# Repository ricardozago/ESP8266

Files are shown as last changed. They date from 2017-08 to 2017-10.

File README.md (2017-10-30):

# Guia inicial do ESP8266

O ESP8266 é um microcontrolador com grande capacidade de processamento (80 MHz de processador com 96 KB de RAM para dados), com suporte a redes Wifi. [Seu artigo na Wikipédia](https://en.wikipedia.org/wiki/ESP8266) é um bom ponto de partida para entender melhor. Ele está disponível em vários empacotamentos, onde a versão chamada de ESP-01 pode ser utilizada como um chip para fornecer acesso Wifi para o Arduino (ironicamente possuindo muito mais capacidade de processamento que o próprio Arduino Uno R3). O ESP8266 sozinho pode ser utilizado no lugar do Arduino utilizando a mesma IDE para processamento, no entanto nosso foco aqui é utilizá-lo como um periférico no Arduino.

Pode ser necessário atualizar o Firmware no ESP-01. A versão mais atual (para a versão com 512 KB, 4 Mb de memória ROM, esp8266_nonos_sdk_v2.0.0_16_08_10) pode ser encontrada na pasta do Github ou [aqui](http://espressif.com/en/support/download/sdks-demos). Aparentemente a versão 2.1 não é compatível com a versão de 4 Mb de memória ROM. Os arquivos para atualização do Firmware eagle.flash.bin e eagle.irom0text.bin estarão no arquivo compactado na pasta bin/at/noboot. Também serão utilizados os arquivos esp_init_data_default.bin e blank.bin na pasta /bin. Para facilitar eles estão na pasta [Firmware AT 4 Mb](https://github.com/ricardozago/ESP8266/tree/master/Firmware%20AT%204%20Mb) deste repositório.

Para gravar o firmware podem ser utilizados diversos softwares. Existe uma ferramenta muito rica escrita em Python chamada [esptool.py](https://github.com/espressif/esptool), no entanto usaremos o gravador (flash_download_tools_v3.4.9.2_0), disponível na pasta ou em seu [site oficial](http://www.espressif.com/en/support/download/other-tools). Para o ESP entrar no modo de gravação da imagem é necessário iniciá-lo com a porta GPIO0 aterrada. Também é possível colocar o reset no terra, aterrar o GPIO0, remover o reset do terra e posteriormente o GPIO0.

O [site do Filipeflop](http://blog.filipeflop.com/wireless/upgrade-de-firmware-do-modulo-esp8266.html) demonstra a montagem do circuito necessária. Também existe um projeto de um shield para o Arduino Uno R3 para facilitar a gravação, disponível [nesta pasta](https://github.com/ricardozago/ESP8266/tree/master/ESP-01%20Firmware%20Flasher), uma imagem da placa é mostrada abaixo.

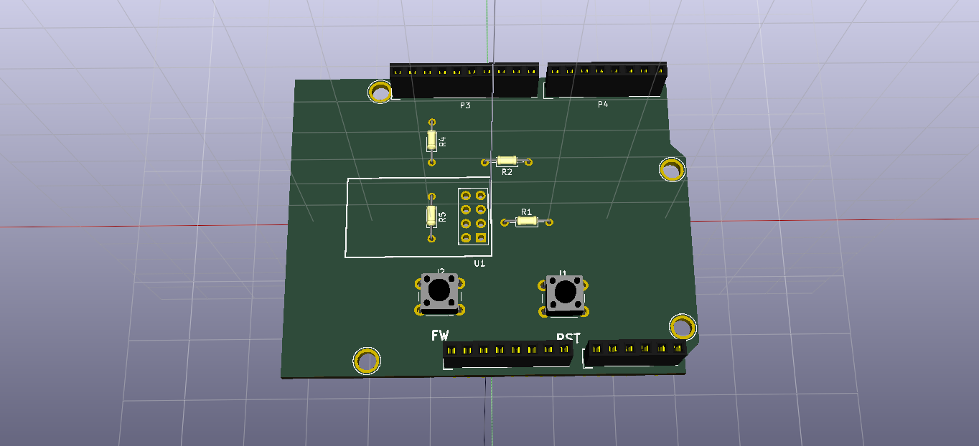
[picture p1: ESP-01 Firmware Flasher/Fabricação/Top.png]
Gravador Placa


Para realizar o microcontrolador Atmel do Arduino não interferir na gravação do Firmware é necessário enviar um Sketch vazio para o Arduino. Como o padrão:

    void setup() {
      // put your setup code here, to run once:

    }

    void loop() {
      // put your main code here, to run repeatedly:

    }

As configurações do gravador de ROM podem ser as mesmas da imagem abaixo:

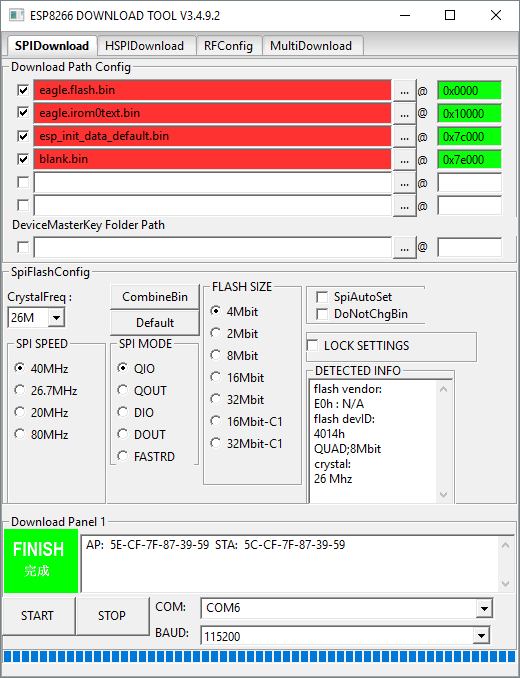
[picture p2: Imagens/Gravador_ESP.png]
Gravador


# Ainda na interface do gravador

O baudrate padrão do ESP é 115200, pode-se utilizar um software de terminal para comunicação, como o [Termite](https://www.compuphase.com/software_termite.htm). Entre nas configurações do termite e em Transmitted text marque a opção:

    Append CR-LF
    
Esta opção adiciona um retorno de cursor e uma nova linha ao comando, necessário para o ESP entender que você acabou de enviar o comando. Para verificar a comunicação com o terminal envia o comando:

    AT

O ESP deverá responder com:

    OK

O Arduino Uno R3, possui apenas uma porta de comunicação UART, que é conectada do chip FTDI para conversão para USB. O ESP pode ser conectado nessa mesma interface, mas isso acarreta problemas de comunicação e dificuldade de programação, já que você terá 3 sistemas "conversando" em uma interface onde apenas deveriam existir 2 sistemas. Uma solução é utilizar uma biblioteca que transforma um GPIO qualquer do Arquino em porta serial, o que acarreta problemas de comunicação em baud-rates elevados, portanto é necessário dominuir o baudrate da interface UART do ESP. O comando abaixo, em um firmware atualizado faz isso:

    AT+UART_DEF=19200,8,1,0,0
    
Agora você já está pronto para conectar o ESP diretamente no Arduino. Utilize o Shield, cujo projeto está disponível na [pasta](https://github.com/ricardozago/ESP8266/tree/master/Arduino%20Shield).

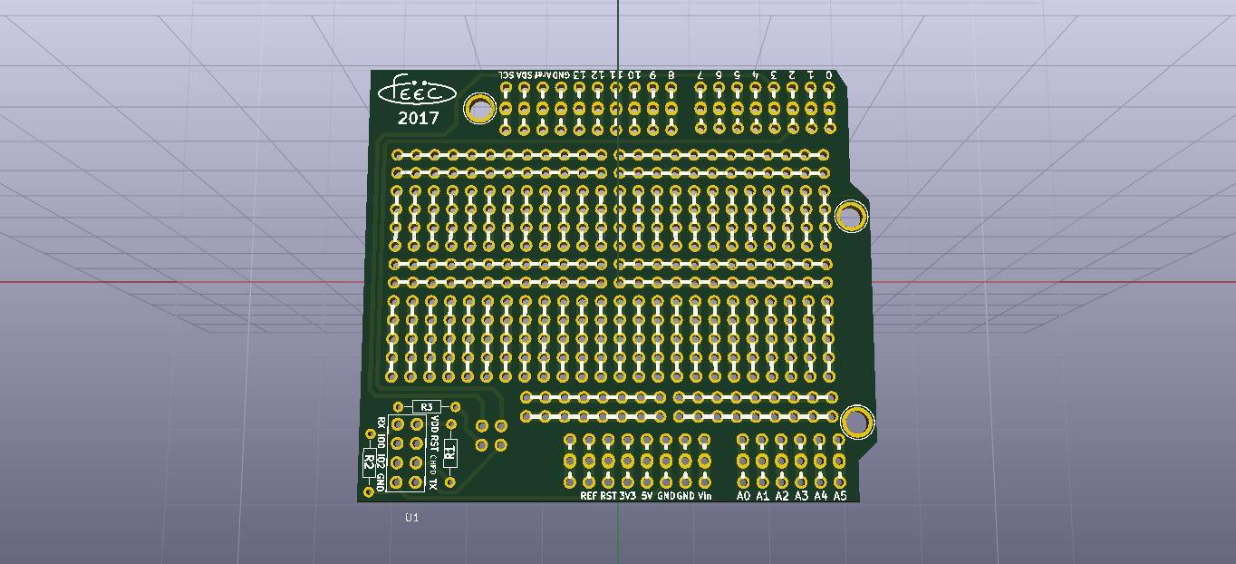
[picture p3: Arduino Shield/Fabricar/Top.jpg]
Shield com ESP

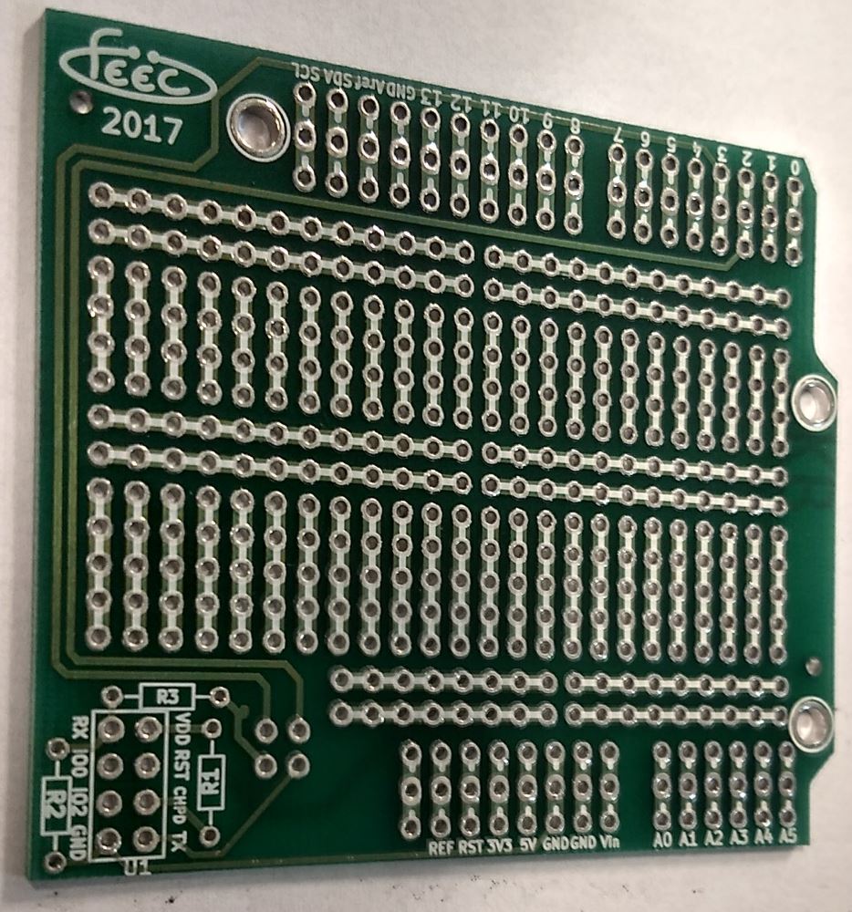
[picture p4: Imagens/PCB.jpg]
Shield fabricado

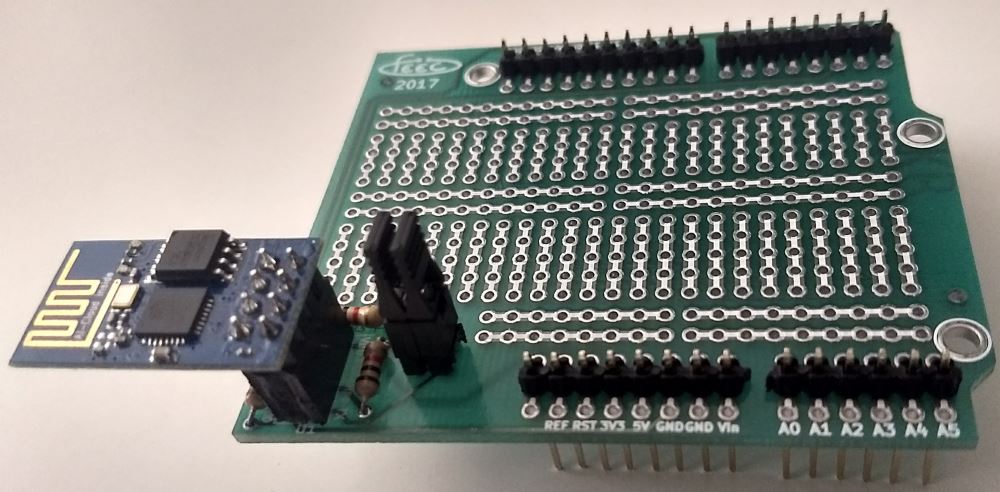
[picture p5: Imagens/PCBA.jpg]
Shield fabricado com ESP


O Sketch [disponível aqui](https://github.com/ricardozago/ESP8266/tree/master/ESP-Espelho) copia os comandos enviados via terminal para o Arduino para o ESP e vice-versa. Isto permite conversar diretamente com o ESP e enteder melhor o seu funcionamento.

Inicialmente envie o comando:

    AT+GMR

A versão do firmware será exibida, por exemplo:

    AT version:1.3.0.0(Jul 14 2016 18:54:01)
    SDK version:2.0.0(656edbf)
    compile time:Jul 19 2016 18:43:55
    OK

Utilize o comando abaixo para verificar em qual modo de operação o ESP está funcionando.

    AT+CWMODE?

Os possíveis modos de operação são:

1 = Cliente
2 = Ponto de acesso
3 = Cliente + Ponto de acesso

O comando abaixo passa para o modo cliente:

    AT+CWMODE=1
    
É possível fazer uma busca nas redes disponíveis com:

    AT+CWLAP
    
Ele retornará uma lista de redes disponíveis. Por exemplo:

    +CWLAP:(5,"eduroam",-86,"d8:c7:c8:78:19:02",1,6,0)
    +CWLAP:(0,"Unicamp-Configuracao",-64,"d8:c7:c8:78:18:d0",1,15,0)

O comando abaixo se conecta a alguma das redes disponíveis:

    AT+CWJAP="ssid","pass"
    
Mostra o IP:

    AT+CIFSR
    
O abaixo se desconecta:

    AT+CWQAP
    
Lembrando, as configurações são salvas. Quando você desliga e liga o ESP, ele continua com as mesmas configurações anteriores, como o baud rate e a última rede conectada.

[Este tutorial do Filipeflop](http://blog.filipeflop.com/wireless/esp8266-arduino-tutorial.html) é um bom ponto de partida para criação de um simples webserver. Apenas alterei o modo de conexão, onde no Filipeflop é necessário um roteador para realizar a conexão, enquanto no meu o próprio ESP é o roteador e os dispositivos se conectam nele. Minha versão modificada está disponível [aqui](https://github.com/ricardozago/ESP8266/tree/master/Arduino%20%2B%20ESP%20-%20p%C3%A1gina%20WEB/Ler_Portas).

Para [alterar o nome da rede](https://github.com/espressif/ESP8266_AT/wiki/CWSAP) no modo AP utilize o comando:

    AT+CWSAP="nome_da_rede","senha",chl,ecn
    
onde se a ecn  é igual a 0 a criptografia está desabilitada. Caso queira habilitar: WEP (1), WPA-PSK (2), WPA2-PSK (3) e WPA/WPA2-PSK (4). Já chl é o canal que a rede é criada.

[Esta página](http://allaboutee.com/2015/01/02/esp8266-arduino-led-control-from-webpage/) possui um interessante exemplo para atuar utilizando uma página Web com o Arduino+ESP. Também disponível [neste repositório](https://github.com/ricardozago/ESP8266/tree/master/Arduino%20%2B%20ESP%20-%20p%C3%A1gina%20WEB/Atuar_IO).

# Observações

Todos os layouts de placa desta pasta utilizam o software [Kicad](http://kicad-pcb.org/), a placas foram desenvolvida utilizando como modelo o Shield para arduino disponível como exemplo do Kicad.

Seu layout foi feito a pedido do professor [Fabiano Fruett](http://www.dsif.fee.unicamp.br/~fabiano/) para uso em disciplinas na Faculdade de Engenharia Elétrica e de Computação (FEEC) da Unicamp.

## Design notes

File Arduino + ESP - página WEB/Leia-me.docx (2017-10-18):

Ler_Portas

O programa Ler_Portas cria uma rede sem fio com o nome padrão do ESP (neste caso ESP_D364D1) sem senha. Conecte-se a essa rede e depois entre no endereço 192.168.4.1.

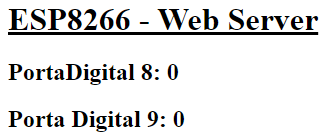
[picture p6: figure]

Esta página mostra o estado das portas 8 e 9.

Atuar_IO

No atuar_io é necessário conectar-se na mesma rede sem fio. Mas a página agora é local, abra o arquivo Página-Web.html que está na mesma pasta.

A página web possui 3 botões, que alteram o estado dos pinos de entrada e saída 11, 12 e 13.

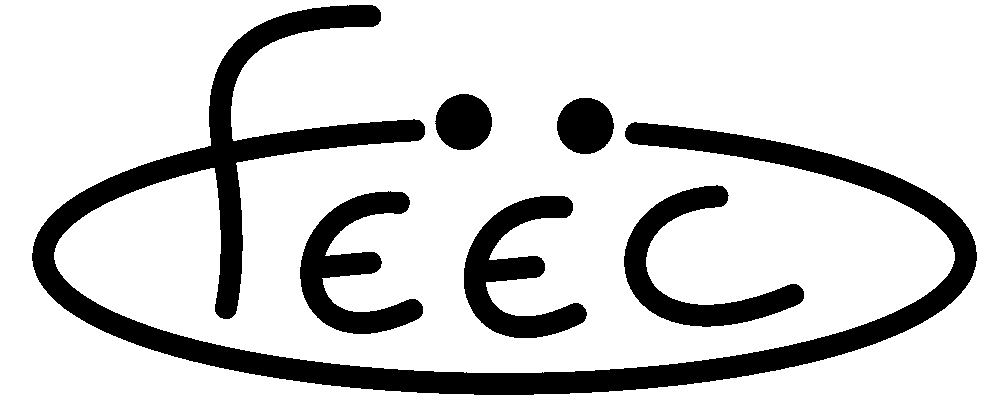
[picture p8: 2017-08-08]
Arduino Shield/feec2.png

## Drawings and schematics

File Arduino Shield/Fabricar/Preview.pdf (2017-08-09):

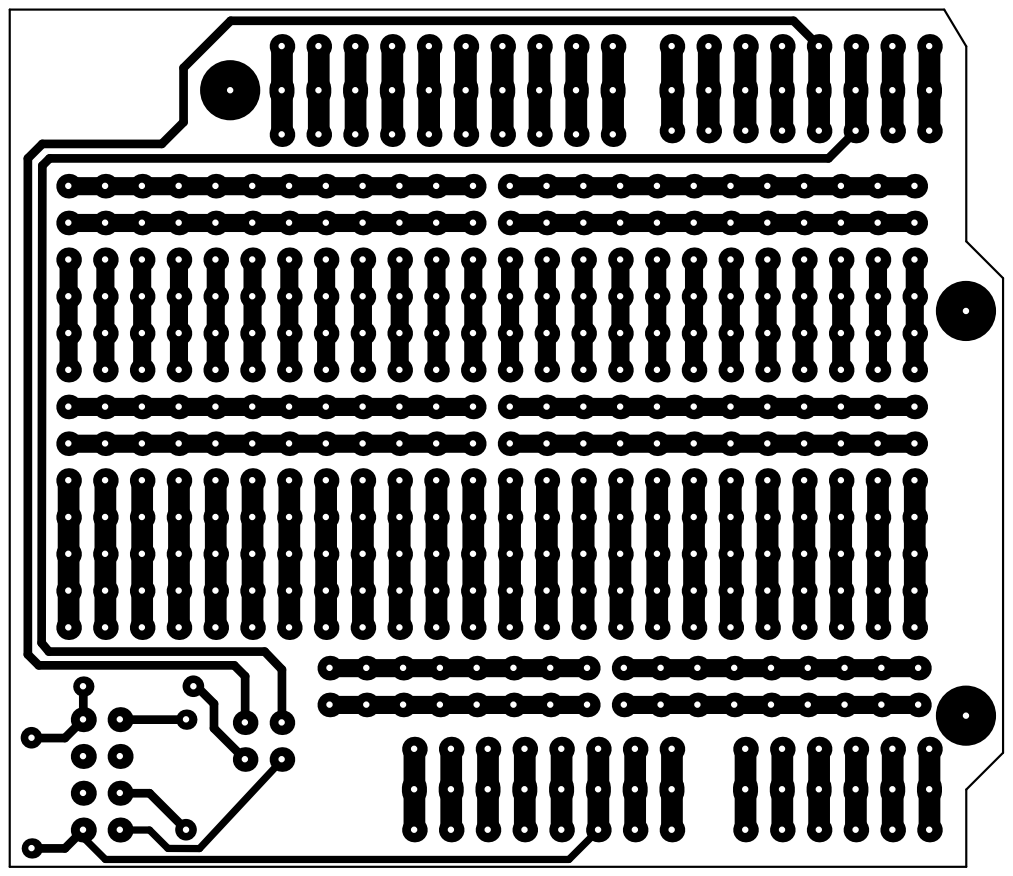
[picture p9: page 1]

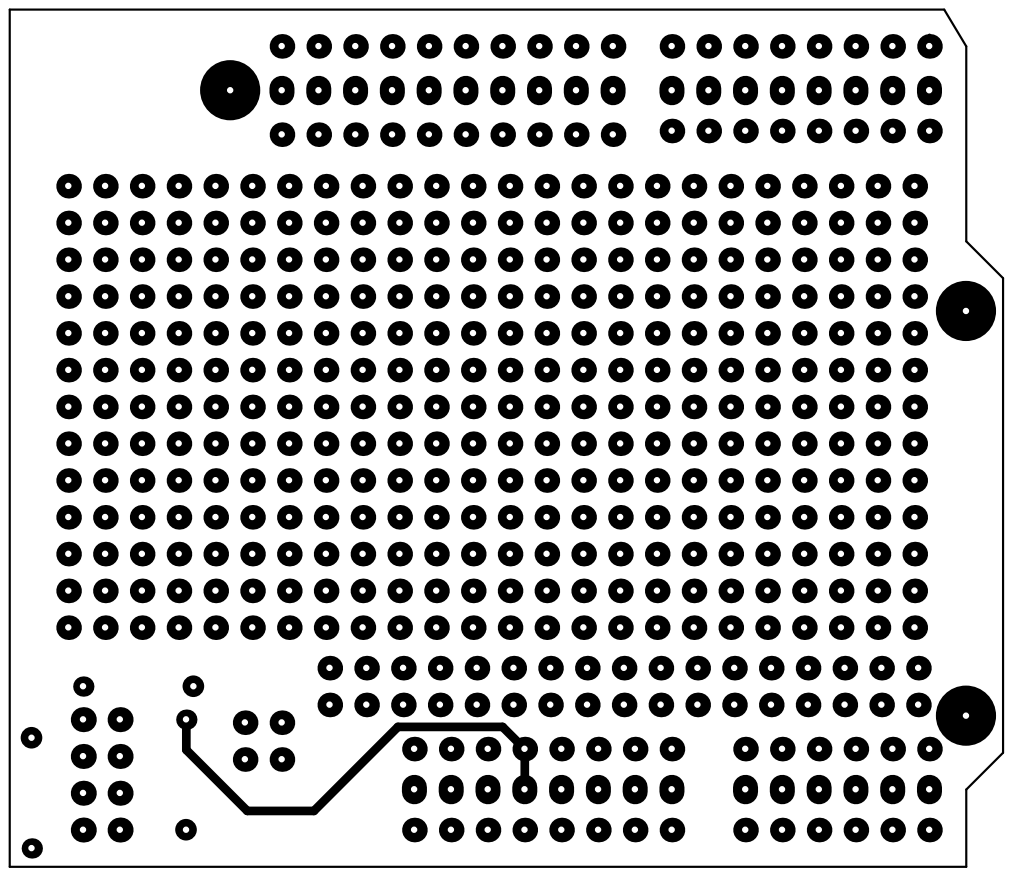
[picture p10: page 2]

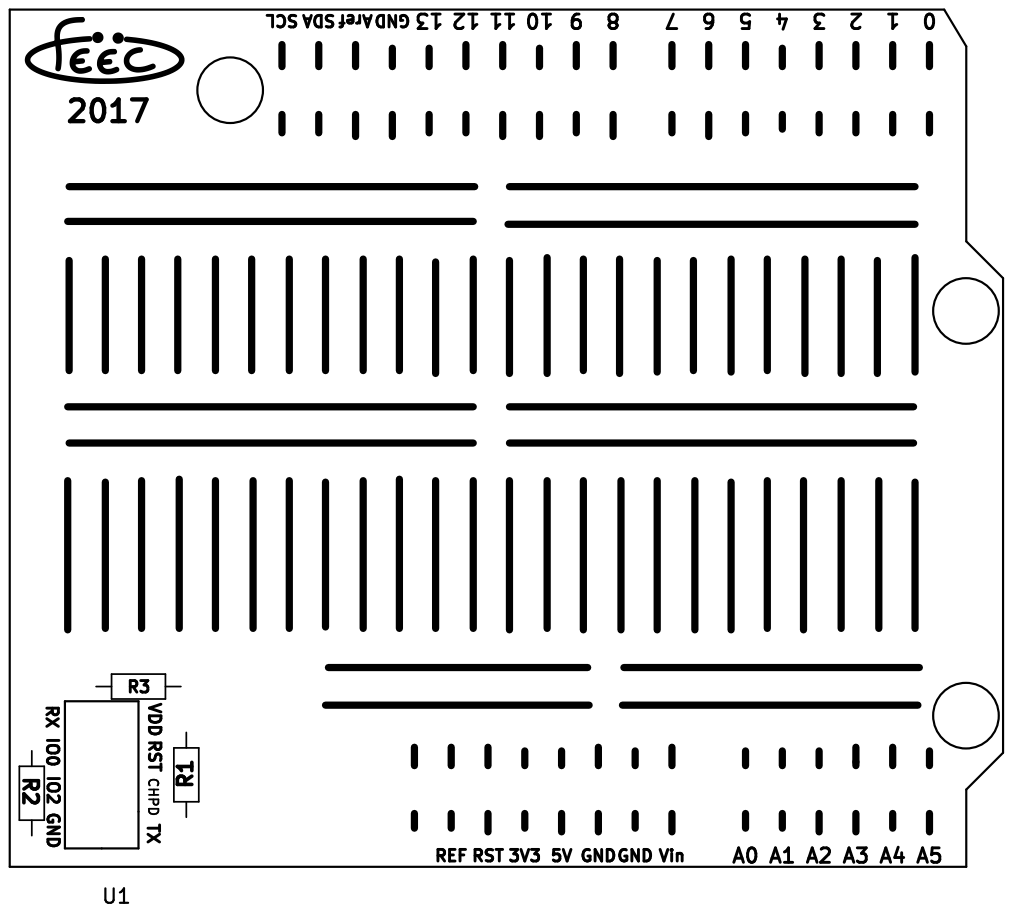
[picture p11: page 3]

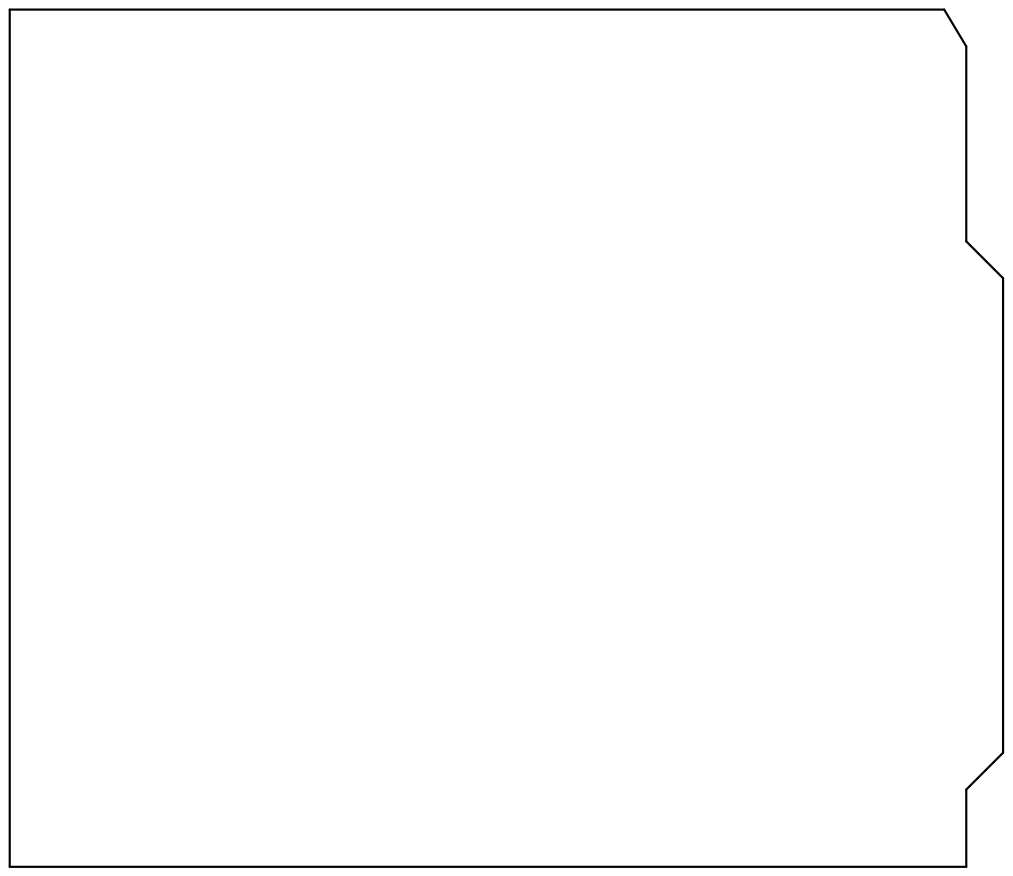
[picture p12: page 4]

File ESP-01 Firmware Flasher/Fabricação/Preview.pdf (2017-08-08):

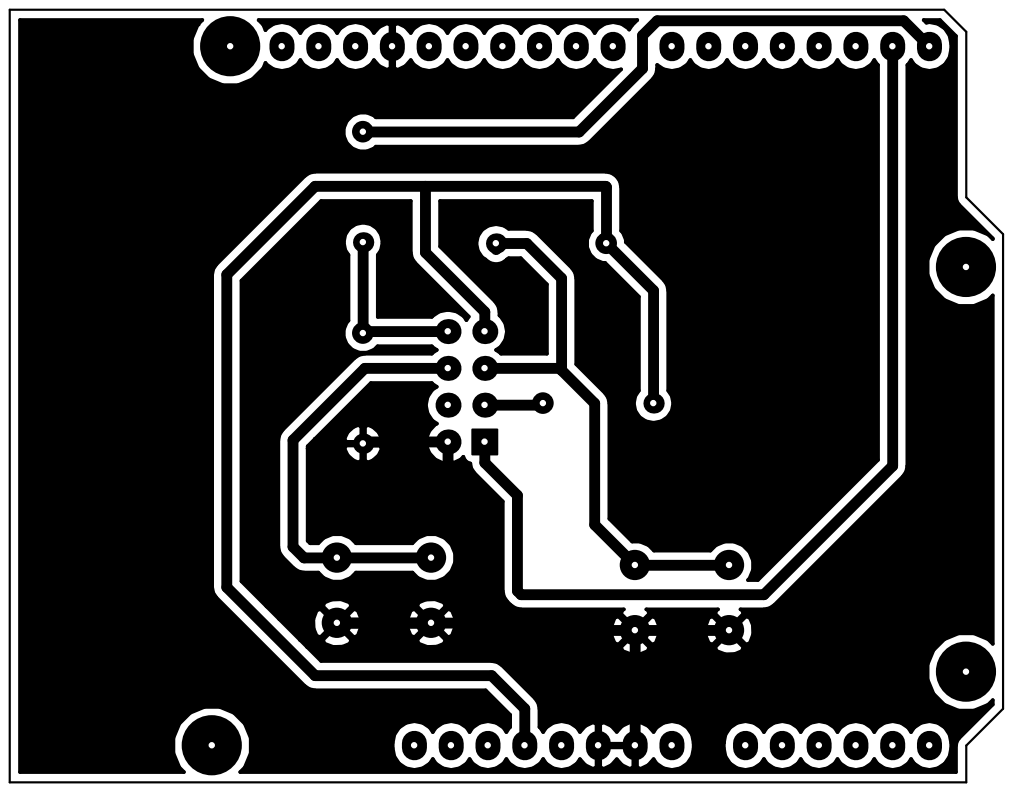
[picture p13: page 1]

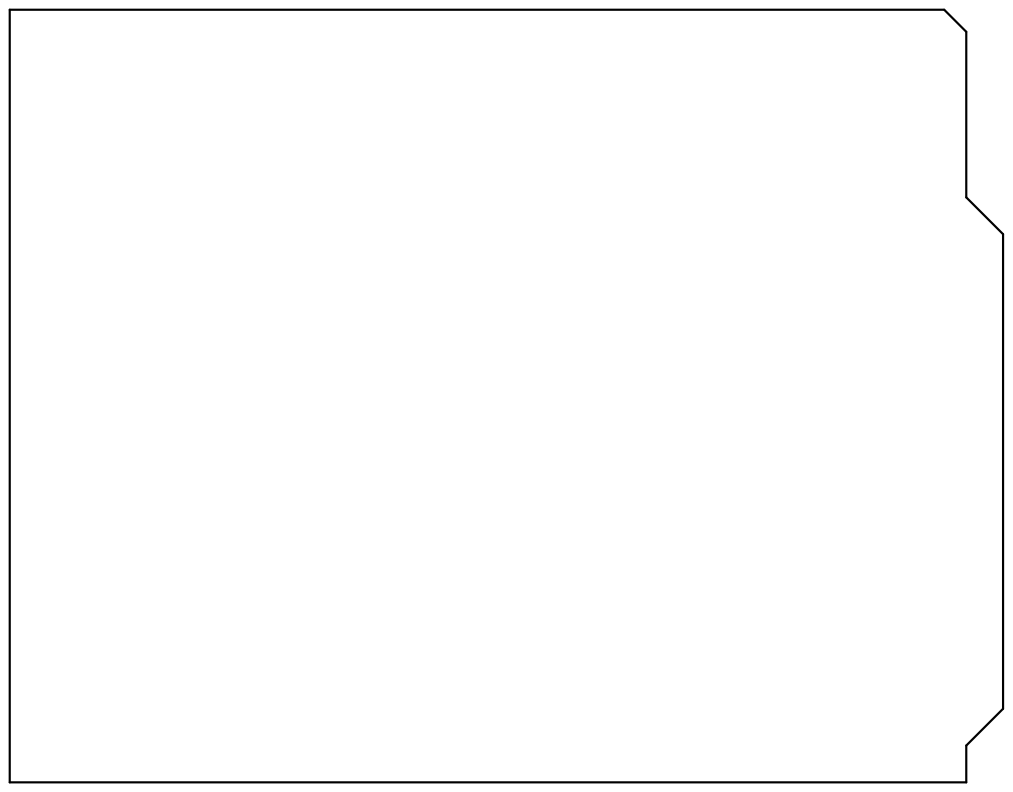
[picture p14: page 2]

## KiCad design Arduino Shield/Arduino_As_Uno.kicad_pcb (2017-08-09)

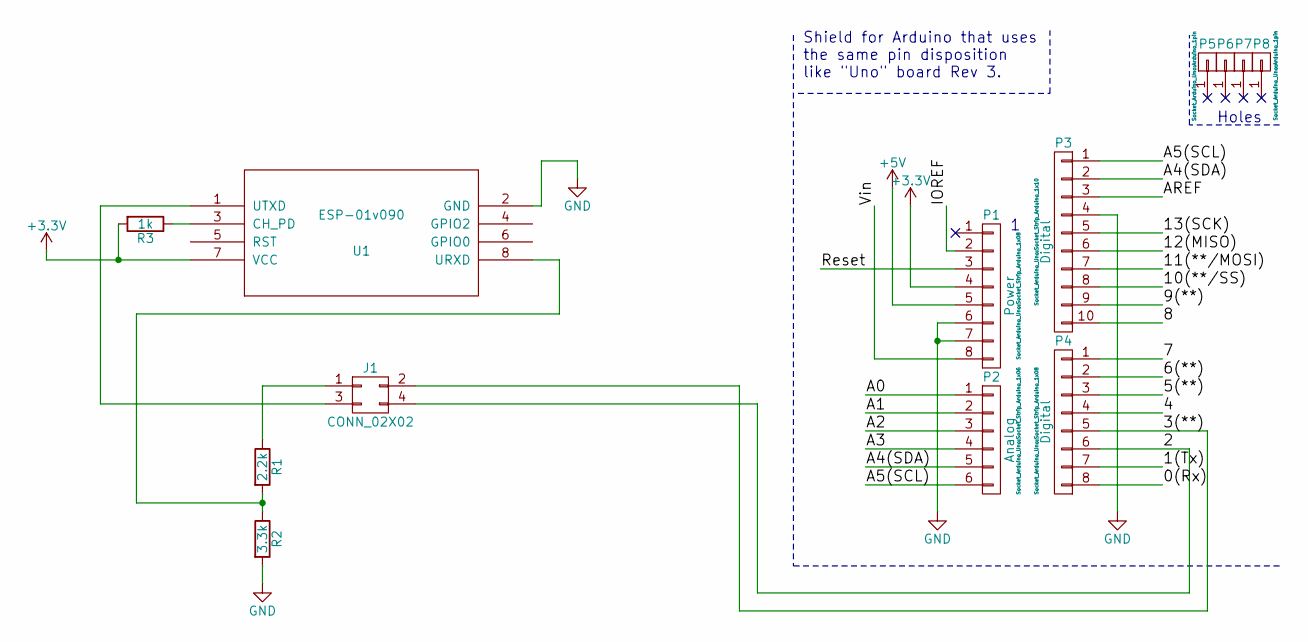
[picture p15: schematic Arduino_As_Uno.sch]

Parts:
J1: CONN_02X02; Pin_Header_Straight_2x02_Pitch2.54mm
P1: Power; Socket_Strip_Arduino_1x08
P2: Analog; Socket_Strip_Arduino_1x06
P3: Digital; Socket_Strip_Arduino_1x10
P4: Digital; Socket_Strip_Arduino_1x08
P5, P6, P7, P8: CONN_01X01; Arduino_1pin
R1: 2.2k; R_Axial_DIN0204_L3.6mm_D1.6mm_P7.62mm_Horizontal
R2: 3.3k; R_Axial_DIN0204_L3.6mm_D1.6mm_P7.62mm_Horizontal
R3: 1k; R_Axial_DIN0204_L3.6mm_D1.6mm_P7.62mm_Horizontal
U1: ESP-01v090; ESP-01

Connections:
+3V3: P1.4, R3.2, U1.7 (VCC)
+5V: P1.5
/0(Rx): P4.8
/1(Tx): P4.7
/2: J1.4, P4.6
/3(**): J1.2, P4.5
/4: P4.4
/5(**): P4.3
/6(**): P4.2
/7: P4.1
/8: P3.10
/9(**): P3.9
/10(**/SS): P3.8
/11(**/MOSI): P3.7
/12(MISO): P3.6
/13(SCK): P3.5
/A0: P2.1
/A1: P2.2
/A2: P2.3
/A3: P2.4
/A4(SDA): P2.5, P3.2
/A5(SCL): P2.6, P3.1
/AREF: P3.3
/IOREF: P1.2
/Reset: P1.3
/Vin: P1.8
GND: P1.6, P1.7, P3.4, R2.2, U1.2 (GND)
unnamed: J1.1, R1.1
unnamed: J1.3, U1.1 (UTXD)
unnamed: R1.2, R2.1, U1.8 (URXD)
unnamed: R3.1, U1.3 (CH_PD)

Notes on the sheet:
Holes
Shield for Arduino that uses the same pin disposition like "Uno" board Rev 3.

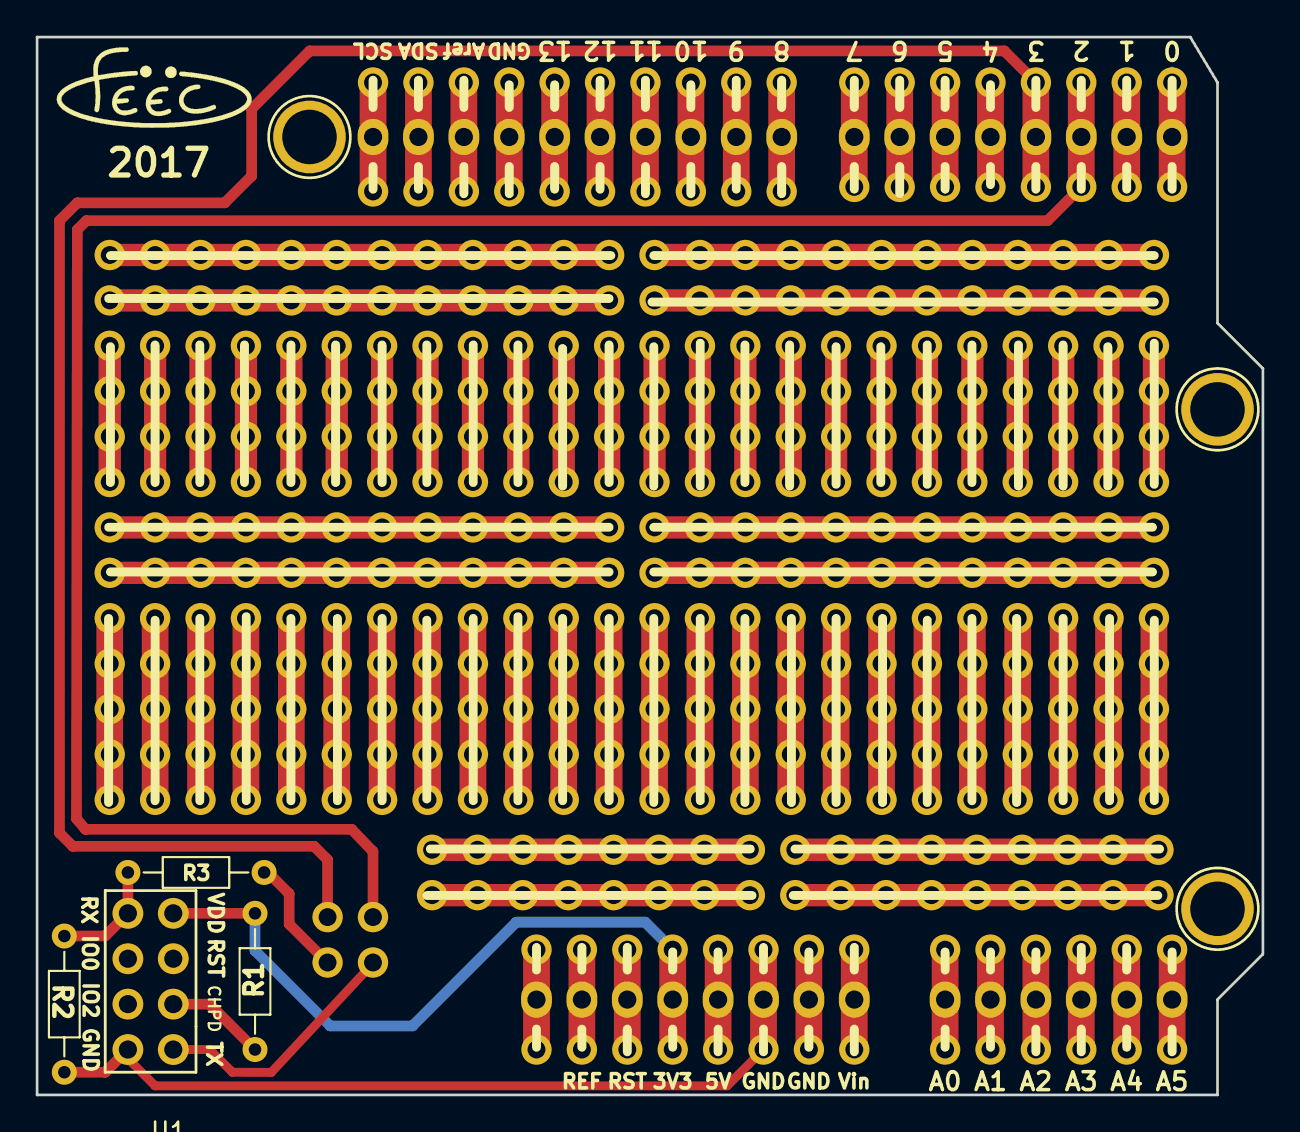
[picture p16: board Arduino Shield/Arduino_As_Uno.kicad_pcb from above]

Board: 2 copper layers, 68.6 x 59.2 mm, 12 parts (0 on the bottom side), 10 nets.

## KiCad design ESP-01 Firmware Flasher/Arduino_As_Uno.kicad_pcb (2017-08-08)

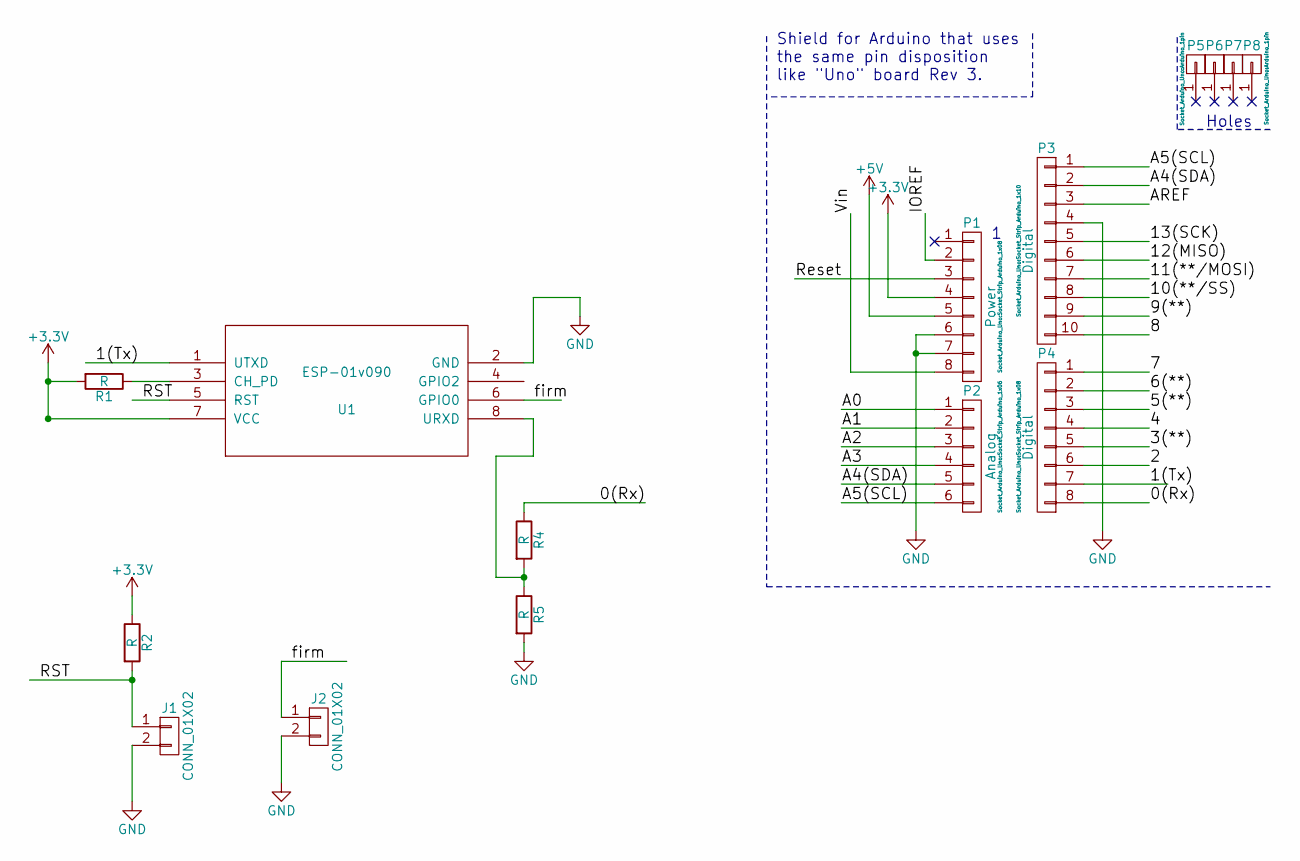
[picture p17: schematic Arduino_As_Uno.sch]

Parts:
J1, J2: CONN_01X02; SW_PUSH_6mm_h5mm
P1: Power; Socket_Strip_Arduino_1x08
P2: Analog; Socket_Strip_Arduino_1x06
P3: Digital; Socket_Strip_Arduino_1x10
P4: Digital; Socket_Strip_Arduino_1x08
P5, P6, P7, P8: CONN_01X01; Arduino_1pin
R1, R2, R4, R5: R; R_Axial_DIN0204_L3.6mm_D1.6mm_P7.62mm_Horizontal
U1: ESP-01v090; ESP-01

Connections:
+3V3: P1.4, R1.2, R2.1, U1.7 (VCC)
+5V: P1.5
/0(Rx): P4.8, R4.1
/1(Tx): P4.7, U1.1 (UTXD)
/2: P4.6
/3(**): P4.5
/4: P4.4
/5(**): P4.3
/6(**): P4.2
/7: P4.1
/8: P3.10
/9(**): P3.9
/10(**/SS): P3.8
/11(**/MOSI): P3.7
/12(MISO): P3.6
/13(SCK): P3.5
/A0: P2.1
/A1: P2.2
/A2: P2.3
/A3: P2.4
/A4(SDA): P2.5, P3.2
/A5(SCL): P2.6, P3.1
/AREF: P3.3
/IOREF: P1.2
/RST: J1.1, R2.2, U1.5 (RST)
/Reset: P1.3
/Vin: P1.8
/firm: J2.1, U1.6 (GPIO0)
GND: J1.2, J2.2, P1.6, P1.7, P3.4, R5.2, U1.2 (GND)
unnamed: R1.1, U1.3 (CH_PD)
unnamed: R4.2, R5.1, U1.8 (URXD)

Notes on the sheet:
Holes
Shield for Arduino that uses the same pin disposition like "Uno" board Rev 3.

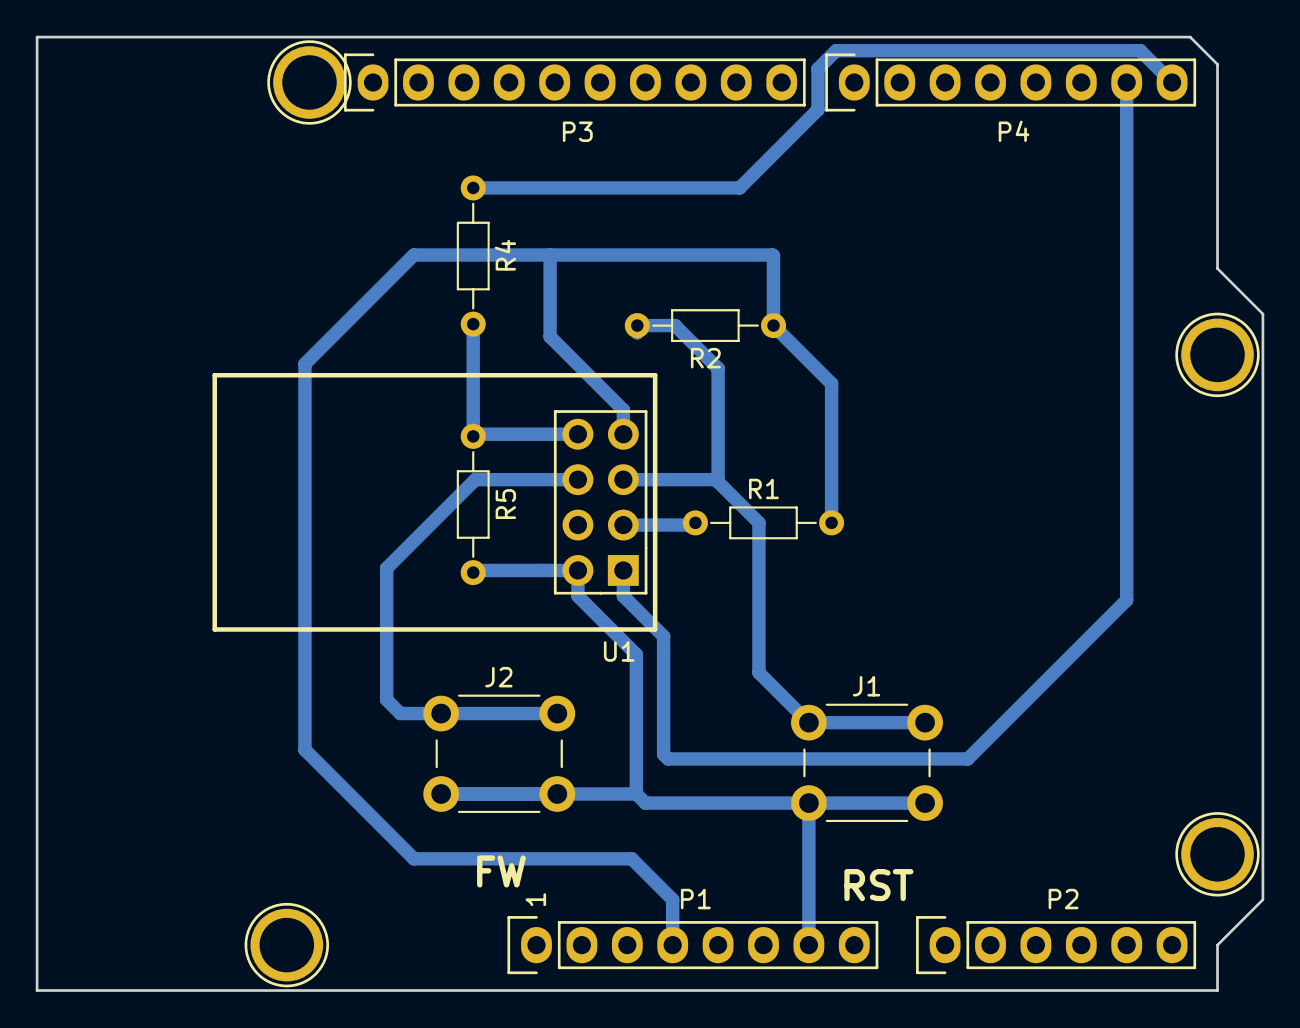
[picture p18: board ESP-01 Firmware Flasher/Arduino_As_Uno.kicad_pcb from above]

Board: 2 copper layers, 68.6 x 53.3 mm, 15 parts (0 on the bottom side), 10 nets.

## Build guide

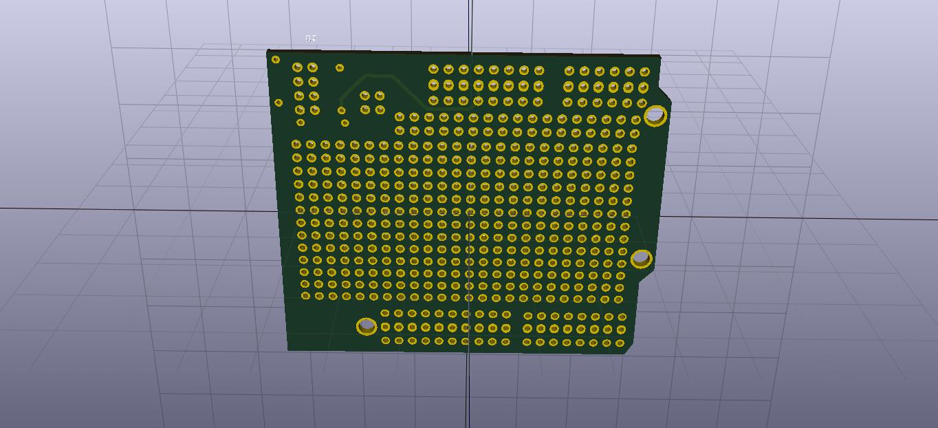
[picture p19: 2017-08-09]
Arduino Shield/Fabricar/Botton.jpg

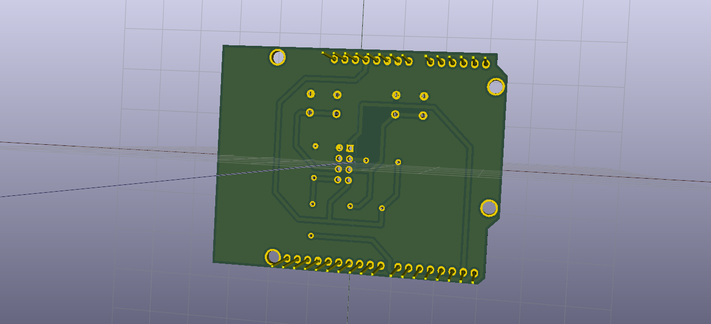
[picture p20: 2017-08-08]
ESP-01 Firmware Flasher/Fabricação/Botton.png

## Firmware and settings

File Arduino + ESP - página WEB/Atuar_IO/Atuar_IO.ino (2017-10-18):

// http://allaboutee.com/2015/01/02/esp8266-arduino-led-control-from-webpage/

#include <SoftwareSerial.h>
 
#define DEBUG true
 
SoftwareSerial esp8266(2,3); // make RX Arduino line is pin 2, make TX Arduino line is pin 3.
                             // This means that you need to connect the TX line from the esp to the Arduino's pin 2
                             // and the RX line from the esp to the Arduino's pin 3
void setup()
{
  Serial.begin(19200);
  esp8266.begin(19200); // your esp's baud rate might be different
  
  pinMode(11,OUTPUT);
  digitalWrite(11,LOW);
  
  pinMode(12,OUTPUT);
  digitalWrite(12,LOW);
  
  pinMode(13,OUTPUT);
  digitalWrite(13,LOW);
   
  sendData("AT+RST\r\n",2000,DEBUG); // reset module
  sendData("AT+CWMODE=2\r\n",1000,DEBUG); // configure as access point
  sendData("AT+CIFSR\r\n",1000,DEBUG); // get ip address
  sendData("AT+CIPMUX=1\r\n",1000,DEBUG); // configure for multiple connections
  sendData("AT+CIPSERVER=1,80\r\n",1000,DEBUG); // turn on server on port 80
}
 
void loop()
{
  if(esp8266.available()) // check if the esp is sending a message 
  {
 
    
    if(esp8266.find("+IPD,"))
    {
     delay(1000); // wait for the serial buffer to fill up (read all the serial data)
     // get the connection id so that we can then disconnect
     int connectionId = esp8266.read()-48; // subtract 48 because the read() function returns 
                                           // the ASCII decimal value and 0 (the first decimal number) starts at 48
          
     esp8266.find("pin="); // advance cursor to "pin="
     
     int pinNumber = (esp8266.read()-48)*10; // get first number i.e. if the pin 13 then the 1st number is 1, then multiply to get 10
     pinNumber += (esp8266.read()-48); // get second number, i.e. if the pin number is 13 then the 2nd number is 3, then add to the first number
     
     digitalWrite(pinNumber, !digitalRead(pinNumber)); // toggle pin    
     
     // make close command
     String closeCommand = "AT+CIPCLOSE="; 
     closeCommand+=connectionId; // append connection id
     closeCommand+="\r\n";
     
     sendData(closeCommand,1000,DEBUG); // close connection
    }
  }
}
 
/*
* Name: sendData
* Description: Function used to send data to ESP8266.
* Params: command - the data/command to send; timeout - the time to wait for a response; debug - print to Serial window?(true = yes, false = no)
* Returns: The response from the esp8266 (if there is a reponse)
*/
String sendData(String command, const int timeout, boolean debug)
{
    String response = "";
    
    esp8266.print(command); // send the read character to the esp8266
    
    long int time = millis();
    
    while( (time+timeout) > millis())
    {
      while(esp8266.available())
      {
        
        // The esp has data so display its output to the serial window 
        char c = esp8266.read(); // read the next character.
        response+=c;
      }  
    }
    
    if(debug)
    {
      Serial.print(response);
    }
    
    return response;
}

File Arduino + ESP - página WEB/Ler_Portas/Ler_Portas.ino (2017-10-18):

// https://www.filipeflop.com/blog/esp8266-arduino-tutorial/

#include <SoftwareSerial.h>

//RX pino 2, TX pino 3
SoftwareSerial esp8266(2, 3);

#define DEBUG true

void setup()
{
  Serial.begin(19200);
  esp8266.begin(19200);

  sendData("AT+RST\r\n", 2000, DEBUG); // reset module
  sendData("AT+CWMODE=2\r\n", 1000, DEBUG); // configure as access point
  sendData("AT+CIFSR\r\n", 1000, DEBUG); // get ip address
  sendData("AT+CIPMUX=1\r\n", 1000, DEBUG); // configure for multiple connections
  sendData("AT+CIPSERVER=1,80\r\n", 1000, DEBUG); // turn on server on port 80
}

void loop()
{
  // Verifica se o ESP8266 esta enviando dados
  if (esp8266.available())
  {
    if (esp8266.find("+IPD,"))
    {
      delay(300);
      int connectionId = esp8266.read() - 48;

      String webpage = "<head><meta http-equiv=""refresh"" content=""3"">";
      webpage += "</head><h1><u>ESP8266 - Web Server</u></h1><h2>Porta";
      webpage += "Digital 8: ";
      int a = digitalRead(8);
      webpage += a;
      webpage += "<h2>Porta Digital 9: ";
      int b = digitalRead(9);
      webpage += b;
      webpage += "</h2>";

      String cipSend = "AT+CIPSEND=";
      cipSend += connectionId;
      cipSend += ",";
      cipSend += webpage.length();
      cipSend += "\r\n";

      sendData(cipSend, 1000, DEBUG);
      sendData(webpage, 1000, DEBUG);

      String closeCommand = "AT+CIPCLOSE=";
      closeCommand += connectionId; // append connection id
      closeCommand += "\r\n";

      sendData(closeCommand, 3000, DEBUG);
    }
  }
}

String sendData(String command, const int timeout, boolean debug)
{
  // Envio dos comandos AT para o modulo
  String response = "";
  esp8266.print(command);
  long int time = millis();
  while ( (time + timeout) > millis())
  {
    while (esp8266.available())
    {
      // The esp has data so display its output to the serial window
      char c = esp8266.read(); // read the next character.
      response += c;
    }
  }
  if (debug)
  {
    Serial.print(response);
  }
  return response;
}

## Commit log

2017-08-08 Add PCBs layouts
    [Arduino_As_Uno.kicad_pcb, Arduino_As_Uno.sch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]
2017-08-08 Update ESP-01 Board
    [Arduino_As_Uno.kicad_pcb]
2017-08-09 Update Silkscreen from PCBA
    [Arduino_As_Uno.kicad_pcb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]
2017-10-18 Add Webpage Arduino
2017-10-18 Atualiza o README para adicionar a parte de webpage.
